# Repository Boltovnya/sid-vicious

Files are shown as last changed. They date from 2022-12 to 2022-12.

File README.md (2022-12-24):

# SID Vicious

SID Vicious is an open source breakout board for the MOS 6582/8580 Sound Interface Device.

## Images

### PCB Front

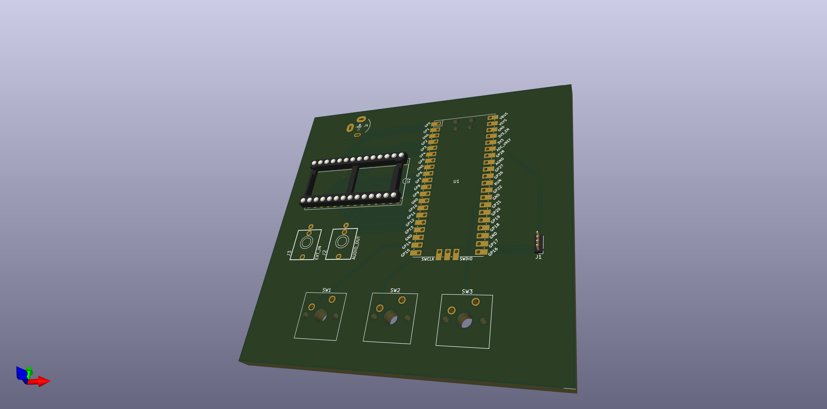
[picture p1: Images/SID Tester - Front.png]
Front


### PCB Rear

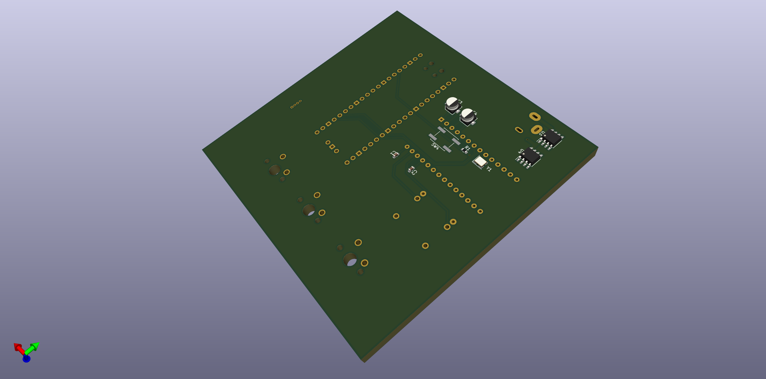
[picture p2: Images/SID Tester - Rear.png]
Rear


## Schematic

The schematic for SID Vicious can be found [here](pdfs/SID%20Tester.pdf)

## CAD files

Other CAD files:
KiCad-RP-Pico-main/SketchUp Model/Pico.skp

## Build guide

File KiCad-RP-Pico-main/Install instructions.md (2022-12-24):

# Install instructions

## 1. Copy the files locally

Copy the `RP-Pico Libraries` folder wherever you like on your computer.

## 2. Install the Raspberry Pi Pico board schema symbol

Use the `KiCad | Preferences | Manage Symbol Libraries...` command to manage the symbol library:



then select the global tab and click on the folder button:



navigate to the `RP-Pico Libraries` folder, select the `MCU_RaspberryPi_and_Boards.kicad_sym` file and open it:



et voilà, the first step is completed:



You can now close the symbol libraries manager window.

## 3. Install the Raspberry Pi Pico board footprint

You can use a similar approach to add the footprint to the footprint libraries manager, but I've found some issues that I've solved using the footprint editor, so here are the steps I suggest you to follow:

Open the footprint editor



wait for the footprints to load... then use the `File | Add Library` command:



confirm the `Global` choice:



and select the `MCU_RaspberriPi_and_Boards.pretty` folder (yes, the folder represent a footprint library on KiCad):



Now the library is installed on KiCad with the Raspberry Pi Pico footprint (double click on it to see it on the editor pane):



Don't close the windows as the next step start from here.

## 4. Install the Raspberry Pi Pico board footprint 3D visual

If not already open, open the the footprint editor

symbol library manager

double click on the `RPi_Pico_SMD_TH` footprint from the `MCU_RaspberriPi_and_Boards` library and then click on the `Footprint properties` icon:



In the footprint properties window, first select the `3D Settings` tab. Please note that the preview shows only the PCB board with the footprint added on step 3, without any 3D representation of the Raspberry Pi Pico board. Now click on the folder icon to add the 3D model:



Navigate to the `RP-Pico Libraries` folder, select the `Pico.wrl` file and wait until the model is shown in the right panel, then confirm with OK:



The model is already scaled and translated to match the footprint:



now close the `Footprint Properties` window, and the `Footprint Editor`, obviously saving the changes.

## Conclusion

Now that you've installed the schema and footprint and added the 3D model to the footprint, you can use the Raspberry Pi Pico board on your KiCad projects.

I've also added a test KiCad Project on the `Test` folder, that you can use to see an example of it.

Have fun!

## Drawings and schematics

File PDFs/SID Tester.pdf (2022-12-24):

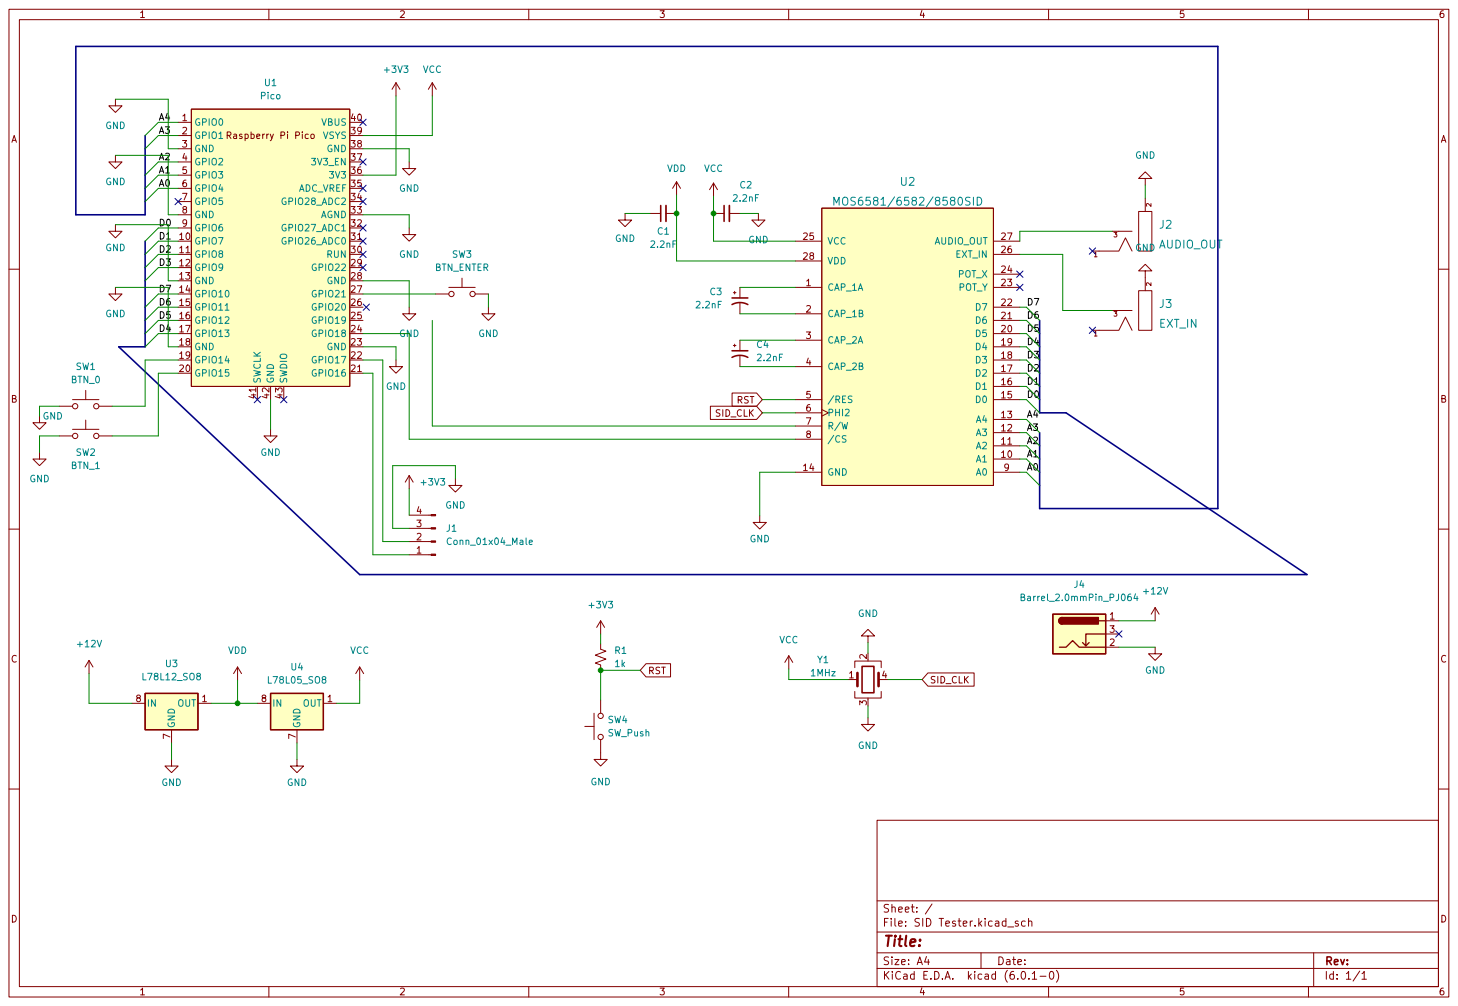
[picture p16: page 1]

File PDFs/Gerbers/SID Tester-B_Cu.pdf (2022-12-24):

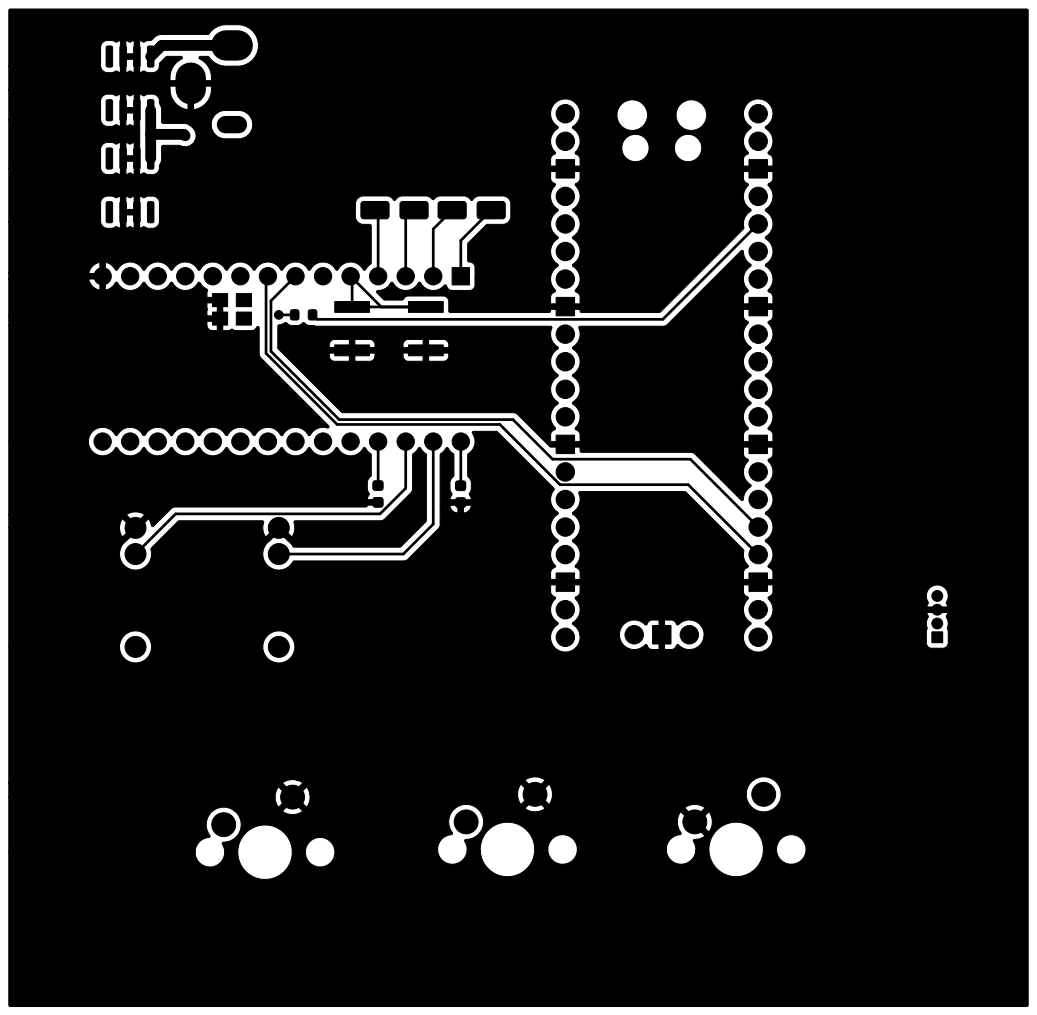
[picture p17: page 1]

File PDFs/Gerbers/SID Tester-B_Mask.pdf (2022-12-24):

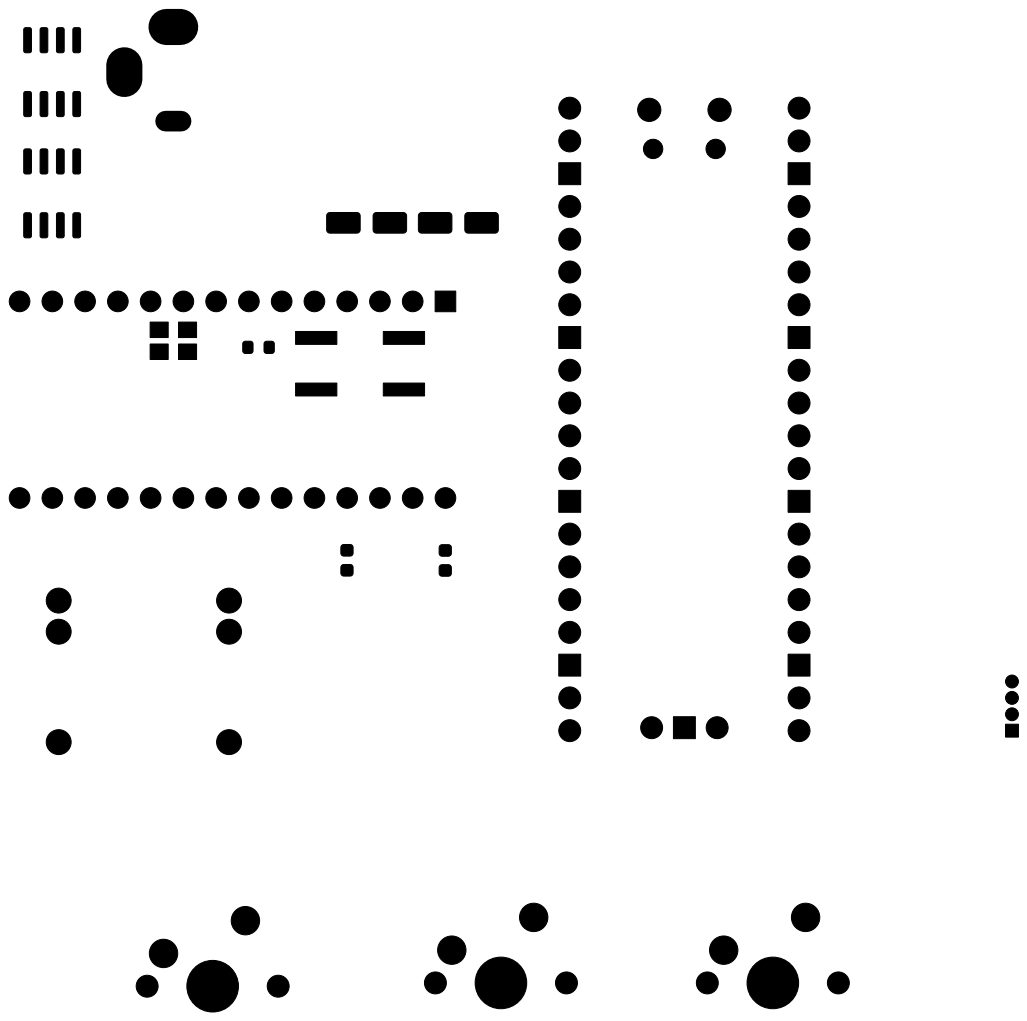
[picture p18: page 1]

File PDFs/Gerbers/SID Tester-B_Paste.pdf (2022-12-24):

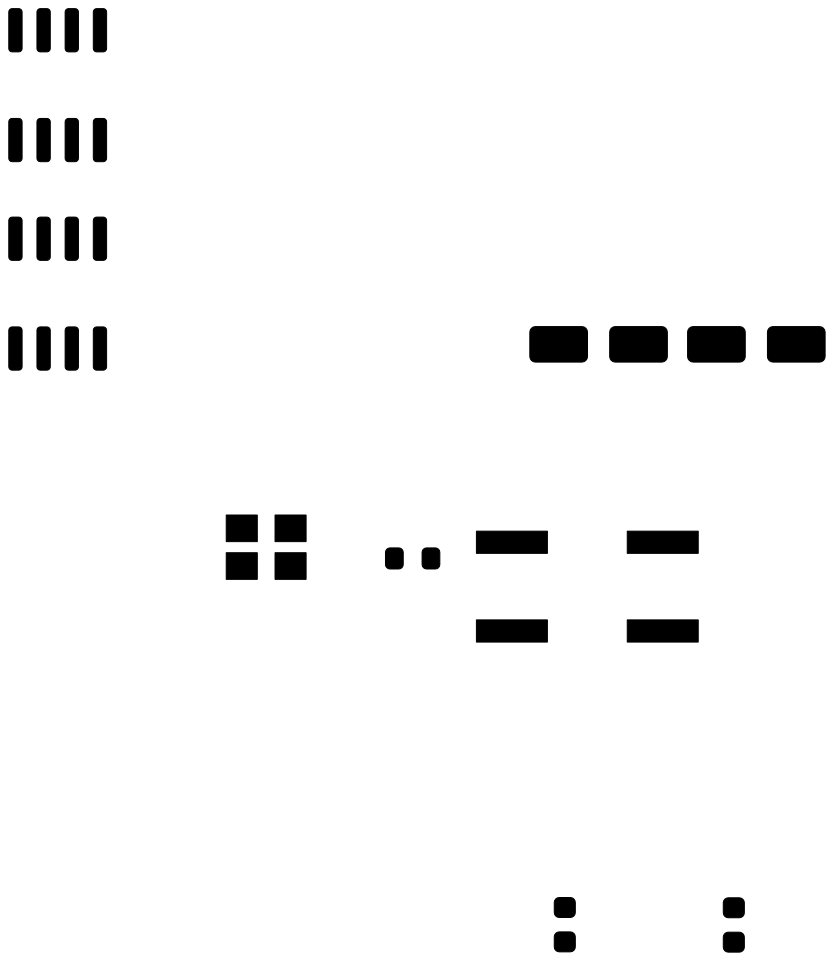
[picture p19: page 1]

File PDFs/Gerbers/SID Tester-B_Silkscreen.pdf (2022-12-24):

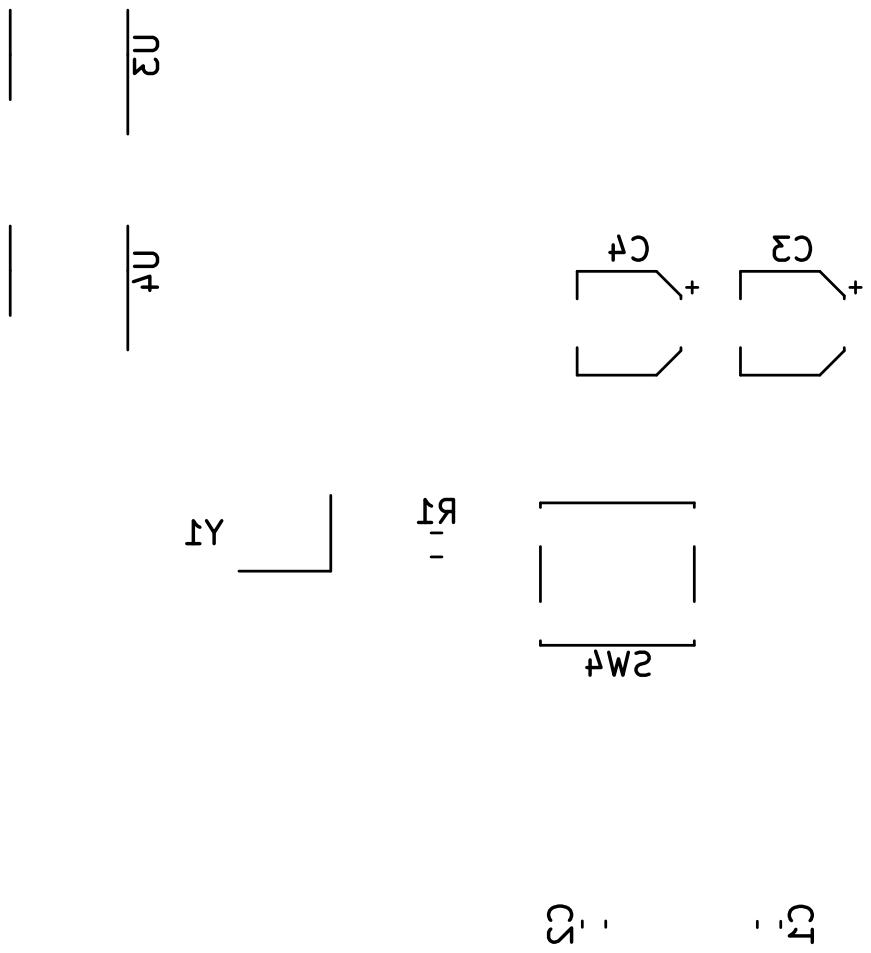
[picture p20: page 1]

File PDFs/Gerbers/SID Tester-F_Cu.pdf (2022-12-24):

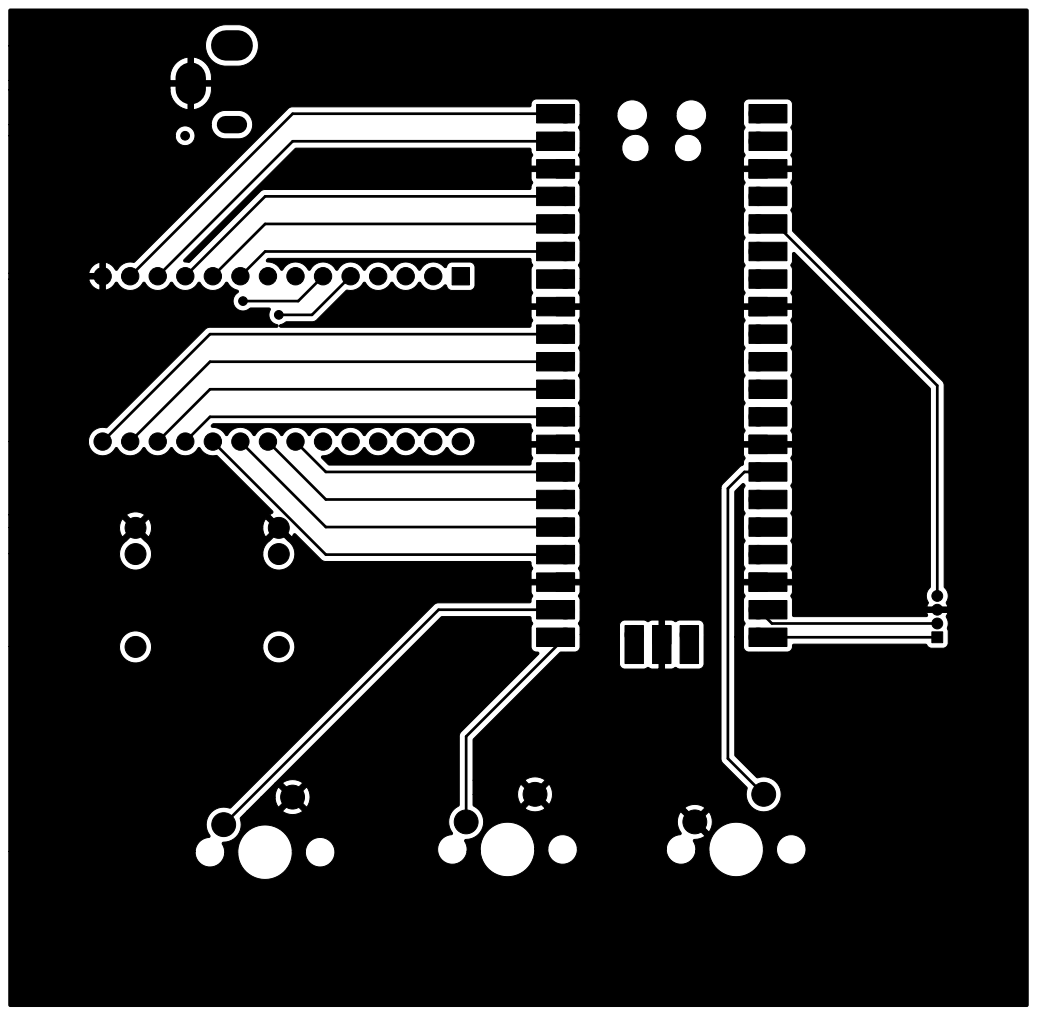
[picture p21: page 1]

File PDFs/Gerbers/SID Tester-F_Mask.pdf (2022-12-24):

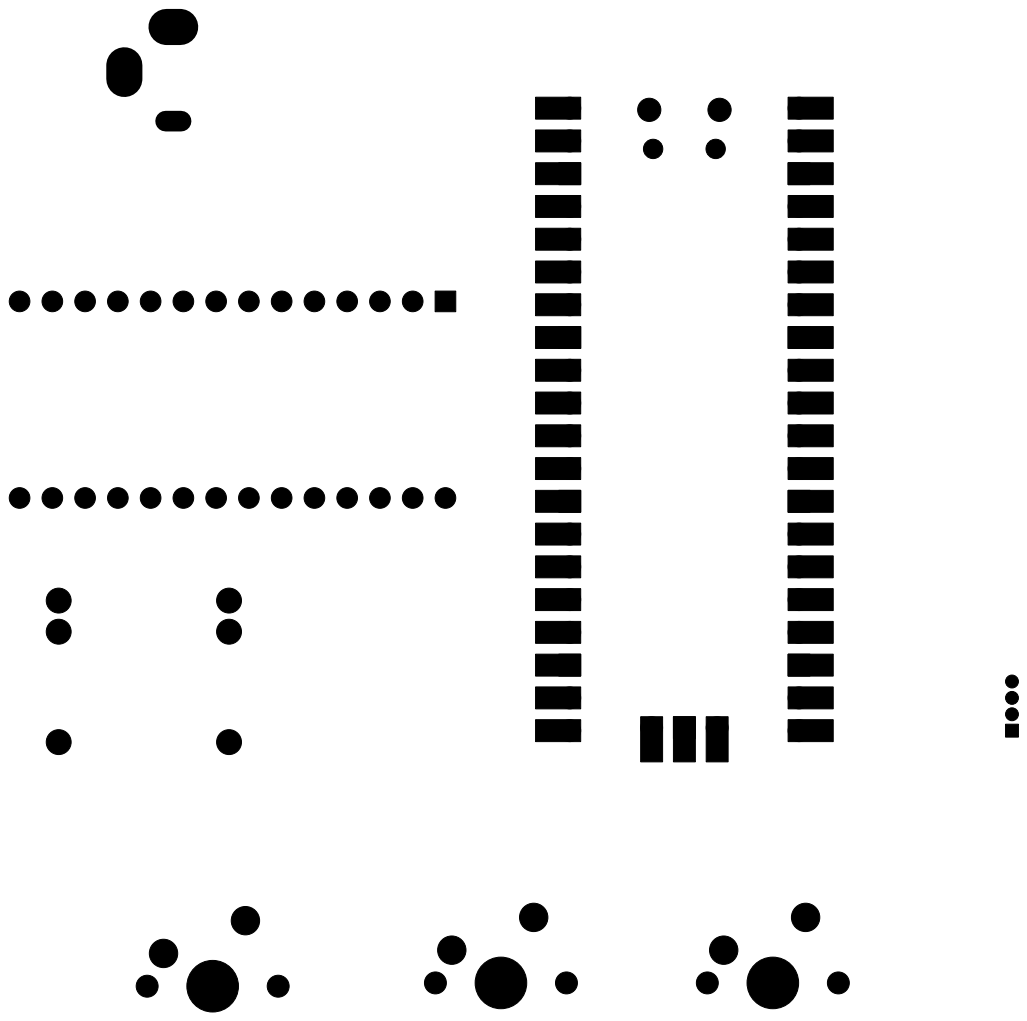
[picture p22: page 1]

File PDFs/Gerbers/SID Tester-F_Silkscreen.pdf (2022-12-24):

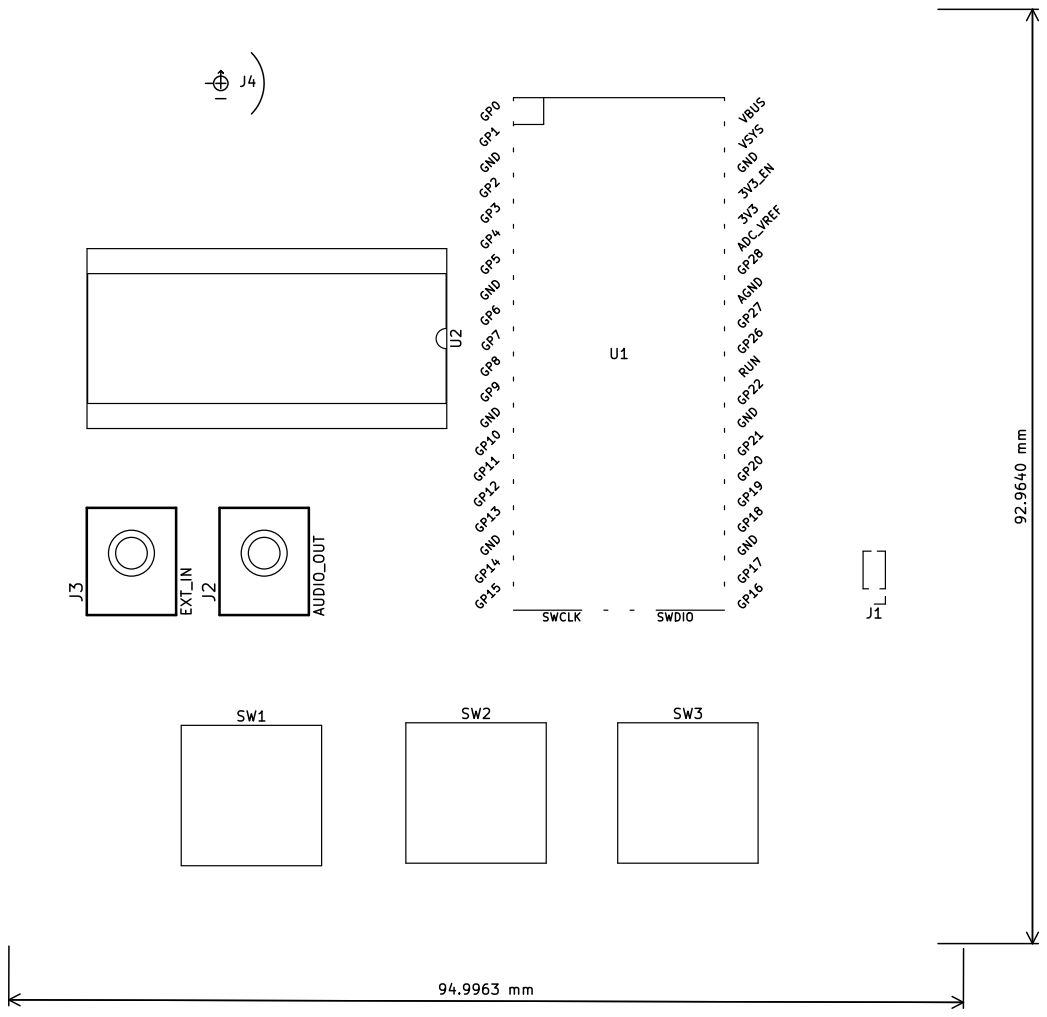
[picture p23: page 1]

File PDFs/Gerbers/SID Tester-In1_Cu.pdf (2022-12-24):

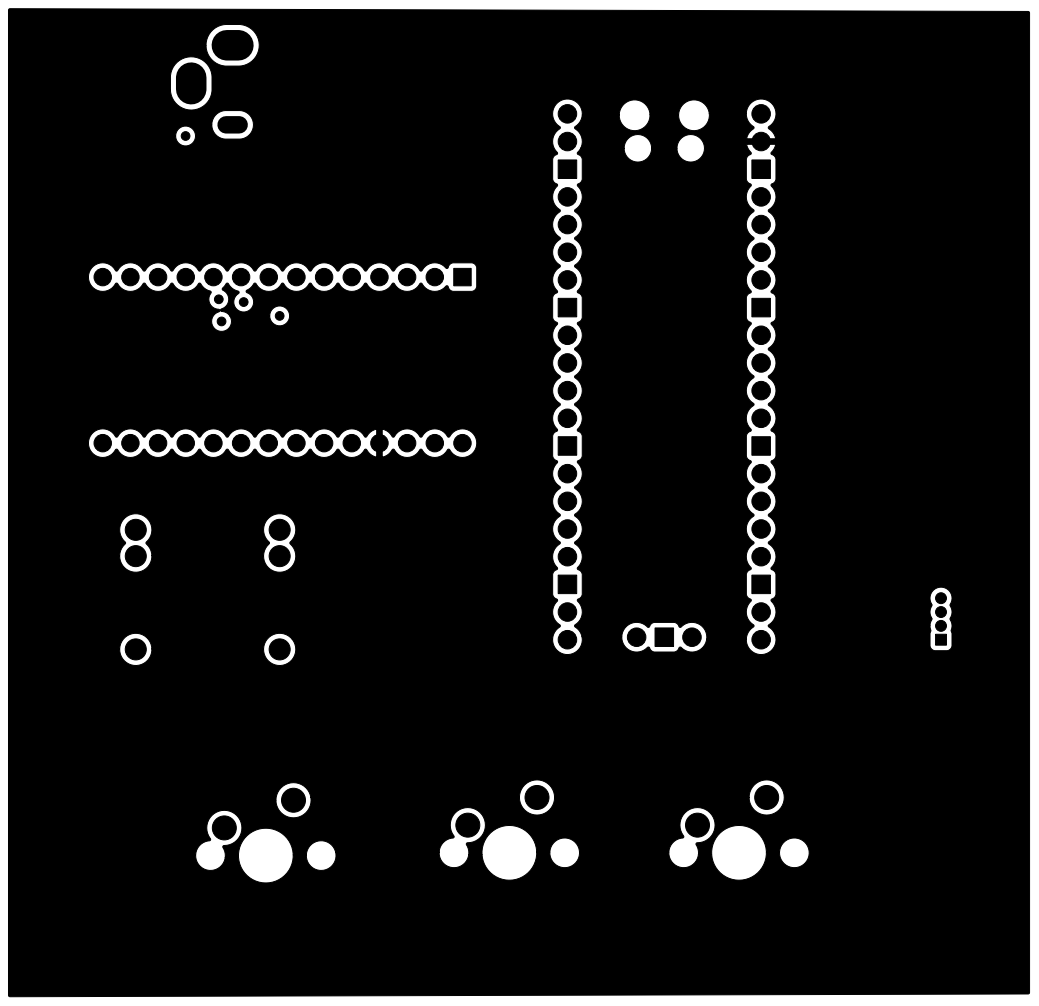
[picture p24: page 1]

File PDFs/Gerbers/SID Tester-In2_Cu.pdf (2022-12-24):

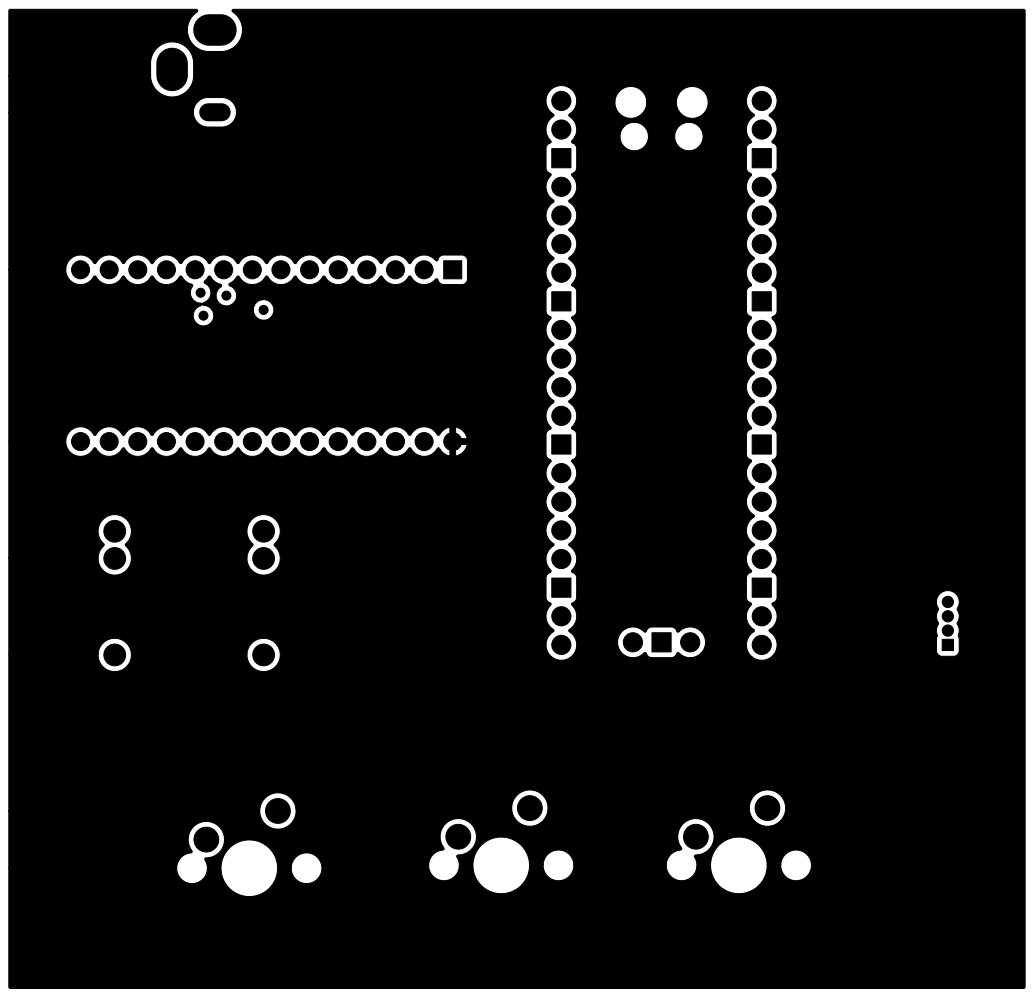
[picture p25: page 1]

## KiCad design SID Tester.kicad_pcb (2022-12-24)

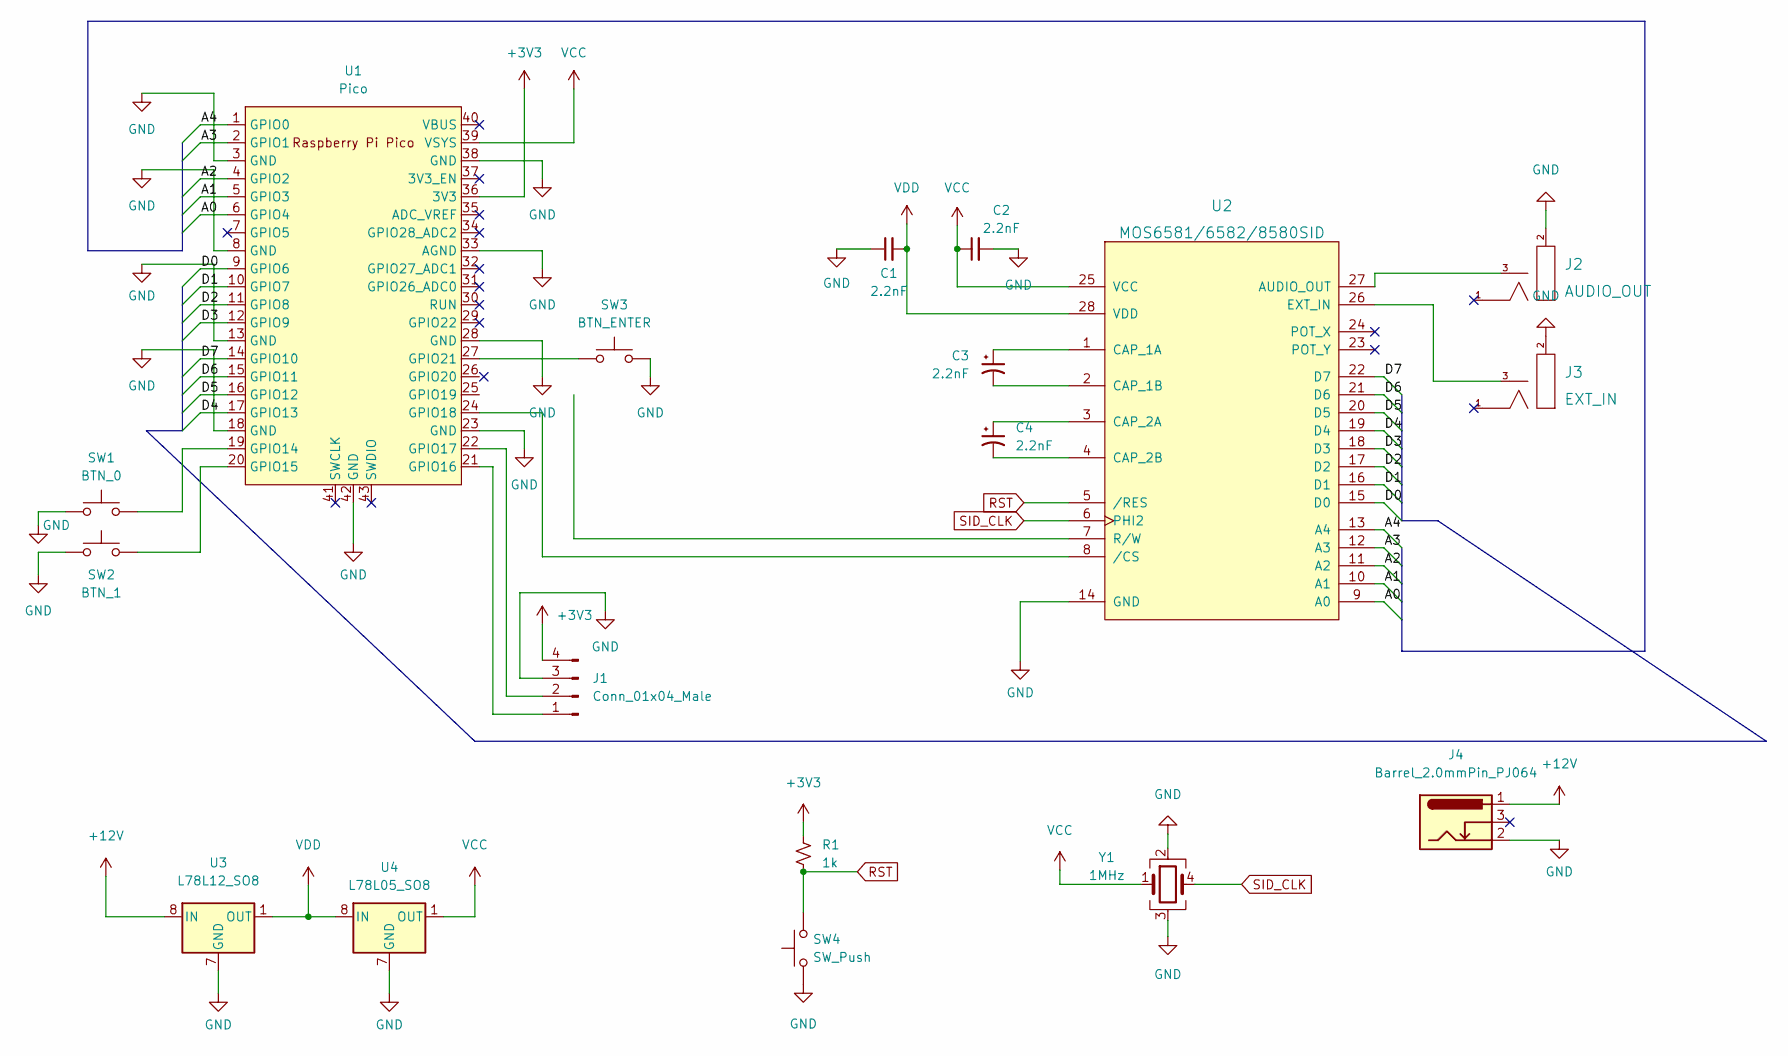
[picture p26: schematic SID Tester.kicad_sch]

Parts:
C1, C2: 2.2nF; C_0603_1608Metric
C3, C4: 2.2nF; CP_Elec_4x3
J1: Conn_01x04_Male; PinHeader_1x04_P1.27mm_Vertical
J2: AUDIO_OUT; EighthInch_PJ398SM; Part Number WQP-WQP518MA
J3: EXT_IN; EighthInch_PJ398SM; Part Number WQP-WQP518MA
J4: Barrel_2.0mmPin_PJ064; Barrel_Vert_PJ064_slotted; Part Number WQP-DC026M (2.0mm center pin)
R1: 1k; R_0603_1608Metric
SW1: BTN_0; SW_Cherry_MX_1.00u_PCB
SW2: BTN_1; SW_Cherry_MX_1.00u_PCB
SW3: BTN_ENTER; SW_Cherry_MX_1.00u_PCB
SW4: SW_Push; SW_SPST_EVQQ2
U1: Pico; RPi_Pico_SMD_TH
U2: MOS6581/6582/8580SID; DIP-28_W15.24mm_Socket
U3: L78L12_SO8; SOIC-8_3.9x4.9mm_P1.27mm
U4: L78L05_SO8; SOIC-8_3.9x4.9mm_P1.27mm
Y1: 1MHz; Crystal_SMD_TXC_7M-4Pin_3.2x2.5mm

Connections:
+3V3: J1.4, R1.1, U1.36 (3V3)
+12V: J4.1, U3.8 (IN)
/A0: U1.6 (GPIO4), U2.9 (A0)
/A1: U1.5 (GPIO3), U2.10 (A1)
/A2: U1.4 (GPIO2), U2.11 (A2)
/A3: U1.2 (GPIO1), U2.12 (A3)
/A4: U1.1 (GPIO0), U2.13 (A4)
/D0: U1.9 (GPIO6), U2.15 (D0)
/D1: U1.10 (GPIO7), U2.16 (D1)
/D2: U1.11 (GPIO8), U2.17 (D2)
/D3: U1.12 (GPIO9), U2.18 (D3)
/D4: U1.17 (GPIO13), U2.19 (D4)
/D5: U1.16 (GPIO12), U2.20 (D5)
/D6: U1.15 (GPIO11), U2.21 (D6)
/D7: U1.14 (GPIO10), U2.22 (D7)
GND: C1.1, C2.2, J1.3, J2.2 (SHEILD), J3.2 (SHEILD), J4.2, SW1.1, SW2.1, SW3.2, SW4.1, U1.3 (GND), U1.8 (GND), U1.13 (GND), U1.18 (GND), U1.23 (GND), U1.28 (GND), U1.33 (AGND), U1.38 (GND), U1.42 (GND), U2.14 (GND), U3.2 (GND), U3.3 (GND), U3.6 (GND), U3.7 (GND), U4.2 (GND), U4.3 (GND), U4.6 (GND), U4.7 (GND), Y1.2, Y1.3
unnamed: C3.1, U2.1 (CAP_1A)
unnamed: C3.2, U2.2 (CAP_1B)
unnamed: C4.1, U2.3 (CAP_2A)
unnamed: C4.2, U2.4 (CAP_2B)
unnamed: SW1.2, U1.19 (GPIO14)
unnamed: SW2.2, U1.20 (GPIO15)
unnamed: SW3.1, U1.27 (GPIO21)
unnamed: J1.1, U1.21 (GPIO16)
unnamed: J1.2, U1.22 (GPIO17)
unnamed: U1.24 (GPIO18), U2.8 (/CS)
unnamed: U1.25 (GPIO19), U2.7 (R/W)
unnamed: J3.3 (SW), U2.26 (EXT_IN)
unnamed: J2.3 (SW), U2.27 (AUDIO_OUT)
RST: R1.2, SW4.2, U2.5 (/RES)
SID_CLK: U2.6 (PHI2), Y1.4
VCC: C2.1, U1.39 (VSYS), U2.25 (VCC), U4.1 (OUT), Y1.1
VDD: C1.2, U2.28 (VDD), U3.1 (OUT), U4.8 (IN)

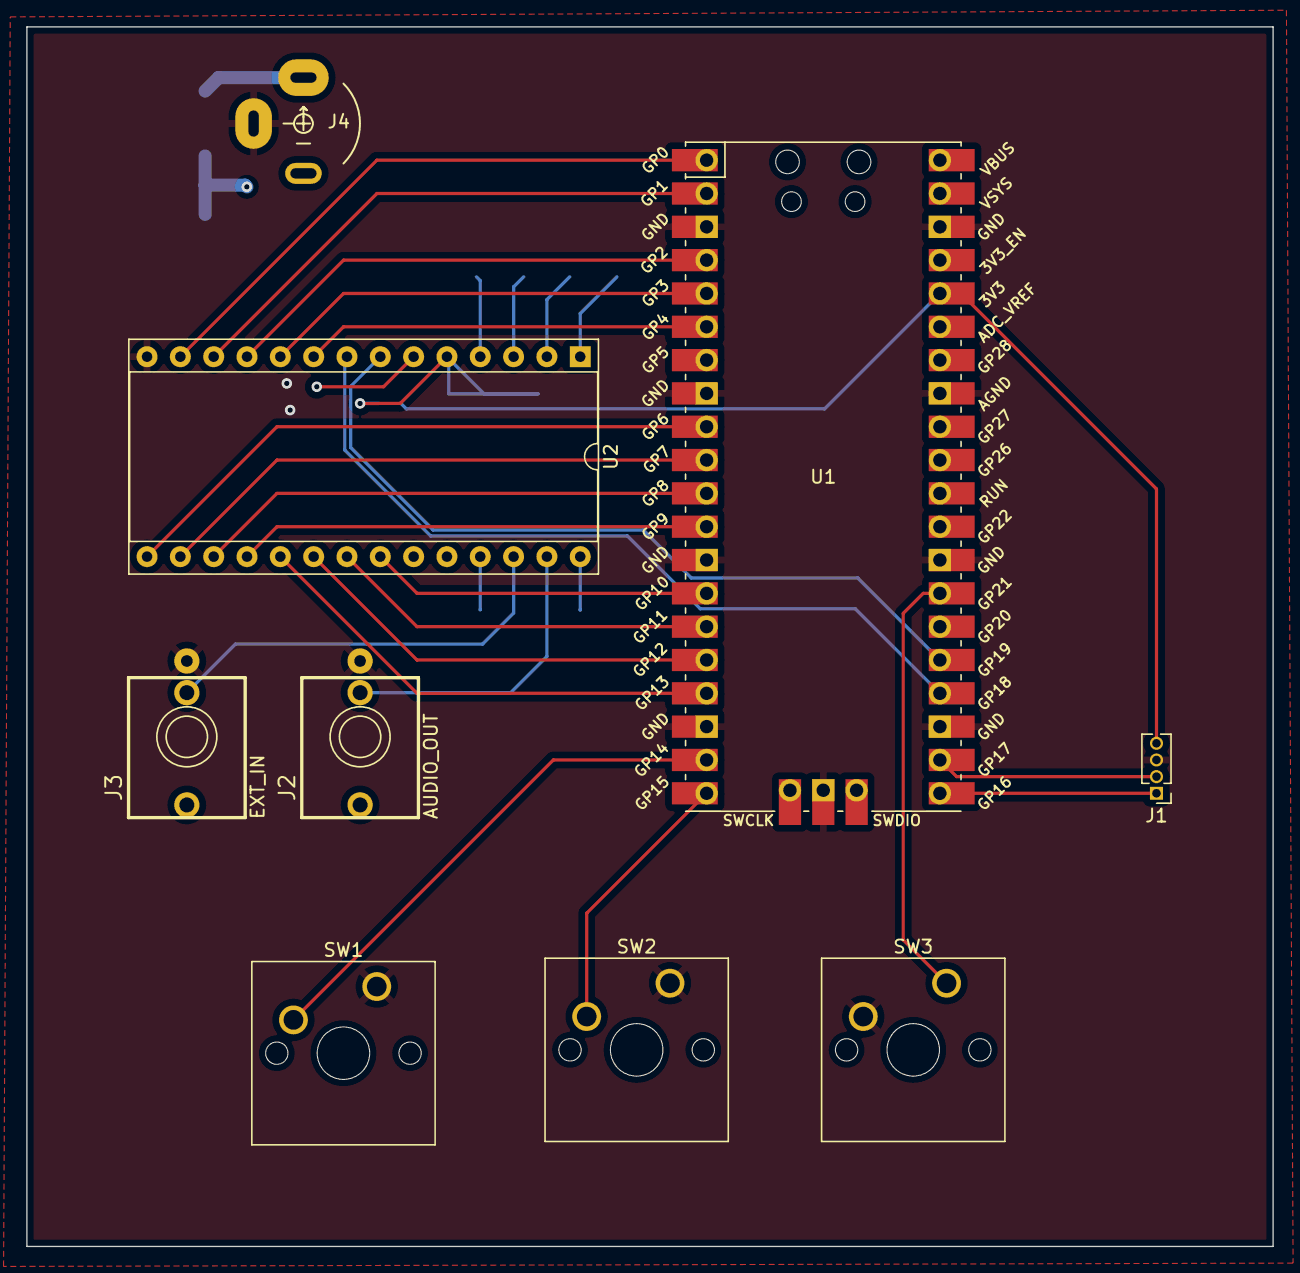
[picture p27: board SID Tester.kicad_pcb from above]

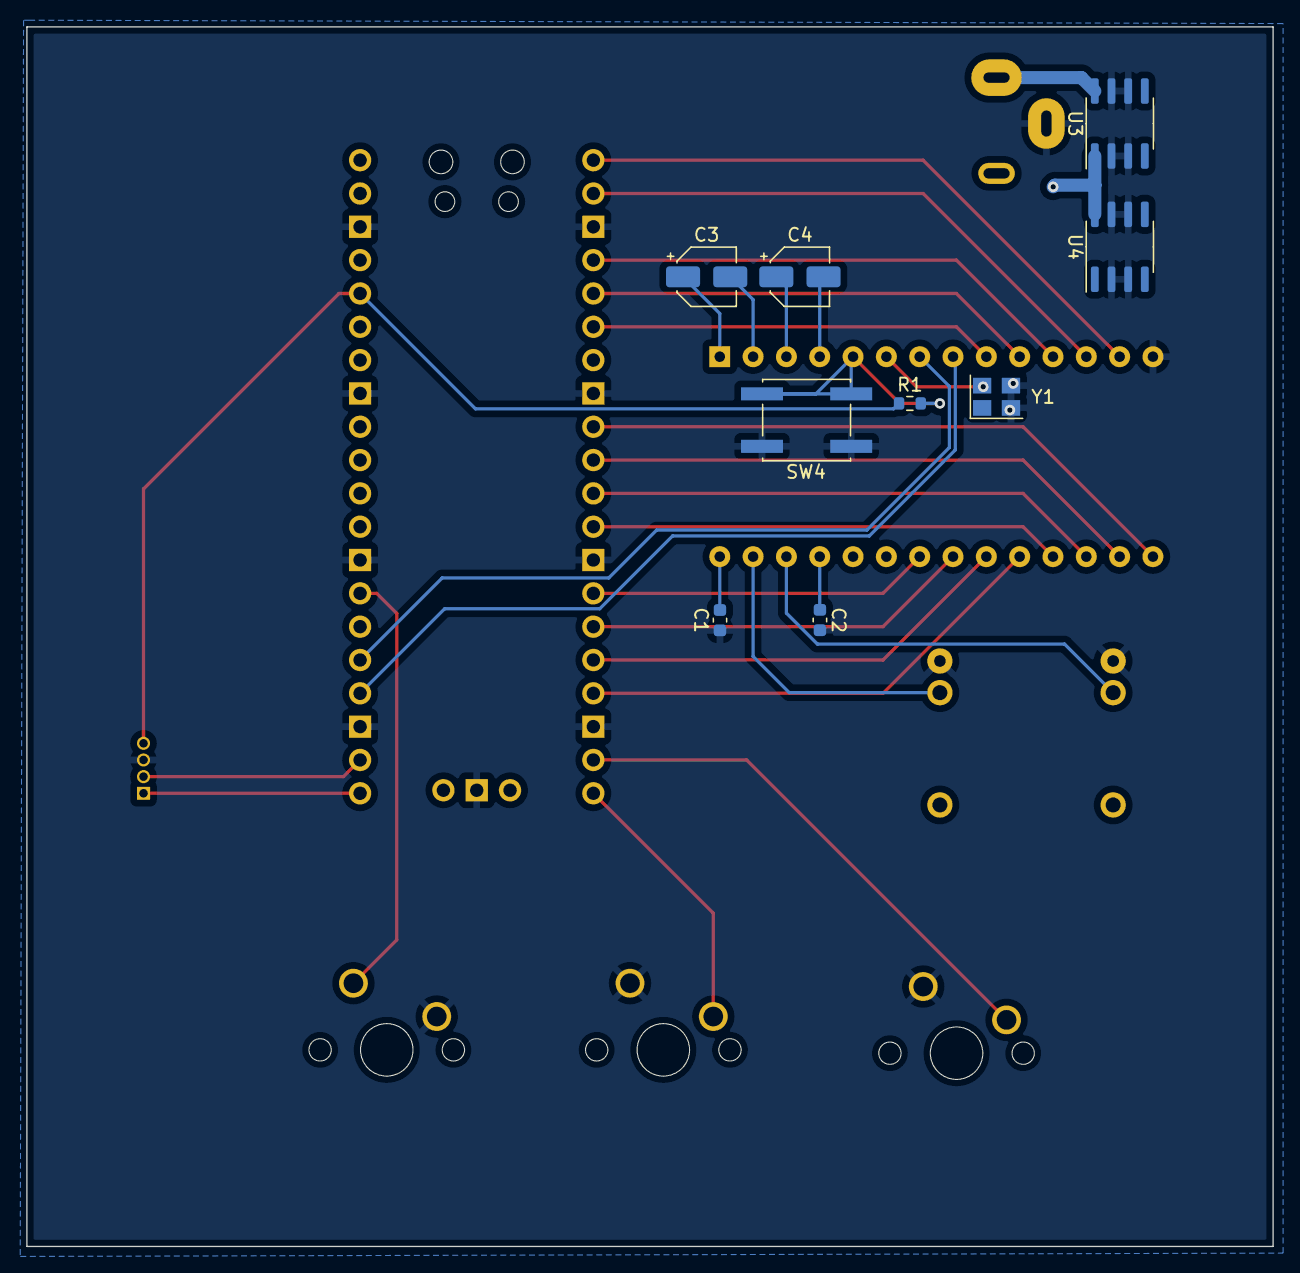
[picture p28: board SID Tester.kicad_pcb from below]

Board: 4 copper layers, 95.0 x 93.0 mm, 18 parts (9 on the bottom side), 33 nets.

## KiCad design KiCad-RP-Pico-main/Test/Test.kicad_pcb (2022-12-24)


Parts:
J1, J2: Conn_01x20; PinSocket_1x20_P1.00mm_Vertical
J3: Conn_01x03; PinSocket_1x03_P1.00mm_Vertical
U1: Pico; RPi_Pico_SMD_TH

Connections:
GND: J1.3, J1.8, J1.13, J1.18, J2.3, J2.13, J2.18, J3.2, U1.3 (GND), U1.8 (GND), U1.13 (GND), U1.18 (GND), U1.23 (GND), U1.28 (GND), U1.38 (GND), U1.42 (GND)
unnamed: J1.1, U1.1 (GPIO0)
unnamed: J1.2, U1.2 (GPIO1)
unnamed: J1.4, U1.4 (GPIO2)
unnamed: J1.5, U1.5 (GPIO3)
unnamed: J1.6, U1.6 (GPIO4)
unnamed: J1.7, U1.7 (GPIO5)
unnamed: J1.9, U1.9 (GPIO6)
unnamed: J1.10, U1.10 (GPIO7)
unnamed: J1.11, U1.11 (GPIO8)
unnamed: J1.12, U1.12 (GPIO9)
unnamed: J1.14, U1.14 (GPIO10)
unnamed: J1.15, U1.15 (GPIO11)
unnamed: J1.16, U1.16 (GPIO12)
unnamed: J1.17, U1.17 (GPIO13)
unnamed: J1.19, U1.19 (GPIO14)
unnamed: J1.20, U1.20 (GPIO15)
unnamed: J2.1, U1.40 (VBUS)
unnamed: J2.2, U1.39 (VSYS)
unnamed: J2.4, U1.37 (3V3_EN)
unnamed: J2.5, U1.36 (3V3)
unnamed: J2.6, U1.35 (ADC_VREF)
unnamed: J2.7, U1.34 (GPIO28_ADC2)
unnamed: J2.8, U1.33 (AGND)
unnamed: J2.9, U1.32 (GPIO27_ADC1)
unnamed: J2.10, U1.31 (GPIO26_ADC0)
unnamed: J2.11, U1.30 (RUN)
unnamed: J2.12, U1.29 (GPIO22)
unnamed: J2.14, U1.27 (GPIO21)
unnamed: J2.15, U1.26 (GPIO20)
unnamed: J2.16, U1.25 (GPIO19)
unnamed: J2.17, U1.24 (GPIO18)
unnamed: J2.19, U1.22 (GPIO17)
unnamed: J2.20, U1.21 (GPIO16)
unnamed: J3.1, U1.43 (SWDIO)
unnamed: J3.3, U1.41 (SWCLK)


Board: 2 copper layers, 43.0 x 65.0 mm, 4 parts (0 on the bottom side), 36 nets.

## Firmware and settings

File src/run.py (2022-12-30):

from machine import Pin, I2C
import ssd1306
from collections import deque
import time


ADDR_BUS = {
    "A0": Pin(4, Pin.OUT),
    "A1": Pin(3, Pin.OUT),
    "A2": Pin(2, Pin.OUT),
    "A3": Pin(1, Pin.OUT),
    "A4": Pin(0, Pin.OUT),
}

DATA_BUS = {
    "D0": Pin(6, Pin.OUT),
    "D1": Pin(7, Pin.OUT),
    "D2": Pin(8, Pin.OUT),
    "D3": Pin(9, Pin.OUT),
    "D4": Pin(13, Pin.OUT),
    "D5": Pin(12, Pin.OUT),
    "D6": Pin(11, Pin.OUT),
    "D7": Pin(10, Pin.OUT),
}

CS = Pin(18, Pin.OUT, Pin.PULL_UP)
RW = Pin(19, Pin.OUT, Pin.PULL_UP)

key_0 = Pin(14, Pin.IN, Pin.PULL_UP)
key_1 = Pin(15, Pin.IN, Pin.PULL_UP)
key_en = Pin(21, Pin.IN, Pin.PULL_UP)

i2c = I2C(0, sda=Pin(16), scl=Pin(17))
display = ssd1306.SSD1306_I2C(128, 64, i2c)

ADDR_LEN = 5
DATA_LEN = 8

addr_reg = []
data_reg = []


def setup():
    global addr_reg
    global data_reg


addr_callback = lambda key: addr_reg.append(key)
data_callback = lambda key: data_reg.append(key)


def send_gpio():
    CS.off()
    RW.off()

    ADDR_BUS["A0"].value(addr_reg[0])
    ADDR_BUS["A1"].value(addr_reg[1])
    ADDR_BUS["A2"].value(addr_reg[2])
    ADDR_BUS["A3"].value(addr_reg[3])
    ADDR_BUS["A4"].value(addr_reg[4])

    DATA_BUS["D0"].value(data_reg[0])
    DATA_BUS["D1"].value(data_reg[1])
    DATA_BUS["D2"].value(data_reg[2])
    DATA_BUS["D3"].value(data_reg[3])
    DATA_BUS["D4"].value(data_reg[4])
    DATA_BUS["D5"].value(data_reg[5])
    DATA_BUS["D6"].value(data_reg[6])
    DATA_BUS["D7"].value(data_reg[7])

    CS.on()
    RW.on()
    addr_reg.clear()
    data_reg.clear()


while True:
    while len(addr_reg) != ADDR_LEN:
        if len(addr_reg) != 5:
            if not key_0.value():
                addr_callback(0)
            if not key_1.value():
                addr_callback(1)
            display.text(f"A: {''.join(str(i) for i in addr_reg)}", 0, 0, 1)
            display.show()
            time.sleep(0.05)
            continue

        if len(data_reg) != 8:
            if not key_0.value():
                data_callback(0)
            if not key_1.value():
                data_callback(1)
            display.text("D: {''.join(str(i) for i in data_reg)}", 0, 15, 2)
            display.show()
            time.sleep(0.05)
            continue

    if not key_en.value():
        send_gpio()
